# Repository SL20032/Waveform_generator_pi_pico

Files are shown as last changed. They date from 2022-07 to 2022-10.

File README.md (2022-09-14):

# Waveform_generator_pi_pico

<p align="center">
  
  
  
  
</p>

## Experimental: project in active development
Do not use 
## Basic Information
Projest aims to build simple waveform generator (with digitaly adjustable amplitude and offset of signal) based around AD9833 DDS chip controled via PC app. With digital and comunication part of the circutry beeing handled by RP2040 on Pi Pico board. 

## Hardware
hardware part of this projest consst of two main elements:
### Analog
Responsible for generating (AD9833) and ampifaing and offsetting (pair of LM7171) analog signal. As well as aditional components needed for example for square wave processing. (attached baord layout require redesign for proper operation of offset capability - work in progress)

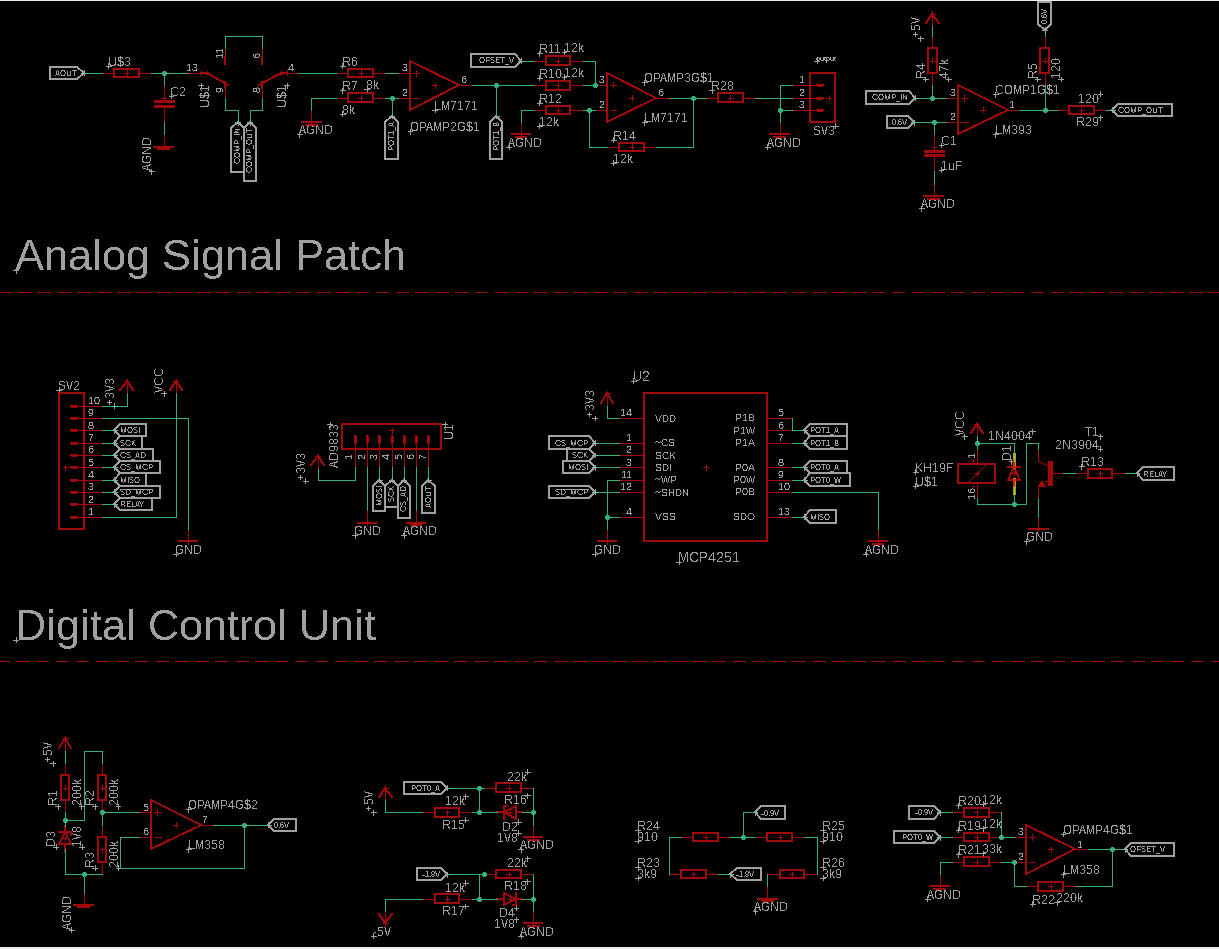
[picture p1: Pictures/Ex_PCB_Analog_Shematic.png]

### Digital
Responsible for controling analog part of circutry using digital potenciometers (MCP4231 / MC4251) integrated on analog board prototype as well as comunication with PC using galvanicly isoleded interfece.
## PC Software
Coming soon

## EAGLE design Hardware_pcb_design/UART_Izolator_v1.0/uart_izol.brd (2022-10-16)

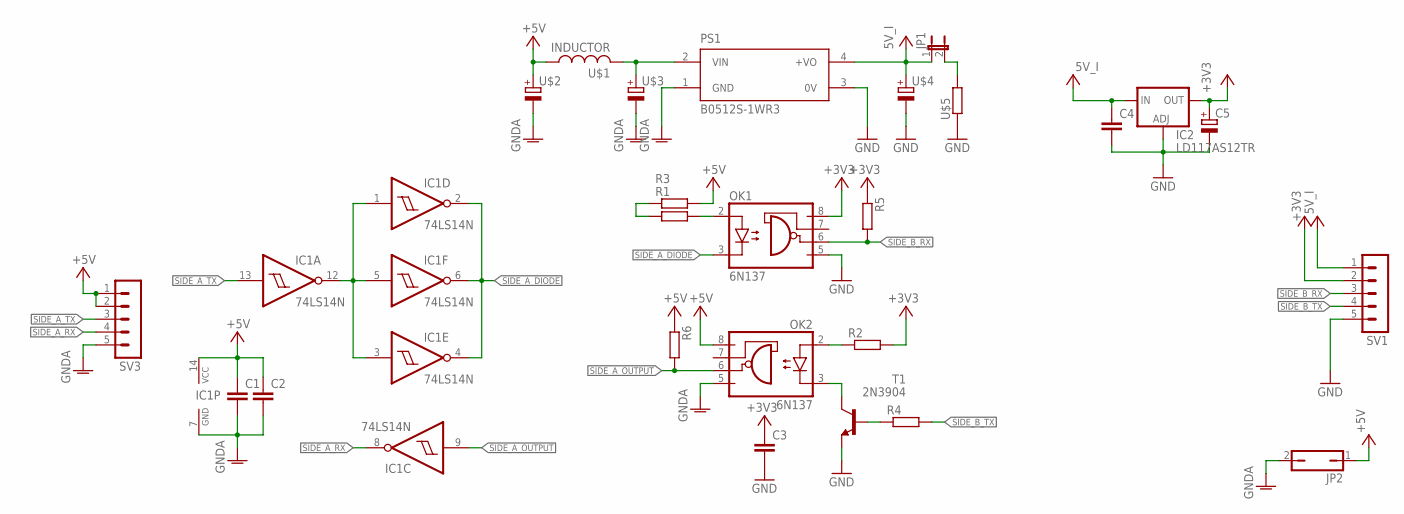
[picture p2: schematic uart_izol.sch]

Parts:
C1, C2, C3, C4: C-EUC0805; C0805
C5: CPOL-EUSMCB; SMC_B
IC1: 74LS14N; DIL14
IC2: LD117AS12TR; SOT223
JP1: JP1E; JP1
JP2: JP1Q; JP1
OK1, OK2: 6N137; DIL08
PS1: B0512S-1WR3; CONV_B0512S-1WR3
R1, R2, R3, R4, R5, R6: R-EU_M0805; M0805
SV1, SV3: MA05-1
T1: 2N3904; TO92
U$1: INDUCTOR; 0207/10
U$2, U$3, U$4: CAPACITOR; E2,5-7
U$5: RESISTOR; 0207/10

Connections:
+3V3: C3.1, C5.+, IC2.4 (OUT), OK1.8 (VCC), R2.2, R5.1, SV1.2
+5V: C1.1, C2.1, IC1.14 (VCC), JP2.1, OK2.8 (VCC), R3.2, R6.1, SV3.1, SV3.2, U$1.1, U$2.+
GND: C3.2, C4.2, C5.-, IC2.1 (ADJ), OK1.5 (GND), PS1.3 (0V), SV1.5, T1.3 (E), U$4.-, U$5.1
GNDA: C1.2, C2.2, IC1.7 (GND), JP2.2, OK2.5 (GND), PS1.1 (GND), SV3.5, U$2.-, U$3.-
unnamed: OK1.2 (A), R1.2
unnamed: OK2.2 (A), R2.1
unnamed: R1.1, R3.1
unnamed: OK2.3 (C), T1.1 (C)
unnamed: JP1.2, U$5.2
unnamed: R4.1, T1.2 (B)
unnamed: PS1.2 (VIN), U$1.2, U$3.+
unnamed: IC1.1 (I), IC1.3 (I), IC1.5 (I), IC1.12 (O)
SIDE_A_DIODE: IC1.2 (O), IC1.4 (O), IC1.6 (O), OK1.3 (C)
SIDE_A_OUTPUT: IC1.9 (I), OK2.6 (VO), R6.2
SIDE_A_RX: IC1.8 (O), SV3.4
SIDE_A_TX: IC1.13 (I), SV3.3
SIDE_B_RX: OK1.6 (VO), R5.2, SV1.3
SIDE_B_TX: R4.2, SV1.4
VCC: C4.1, IC2.3 (IN), JP1.1, PS1.4 (+VO), SV1.1, U$4.+

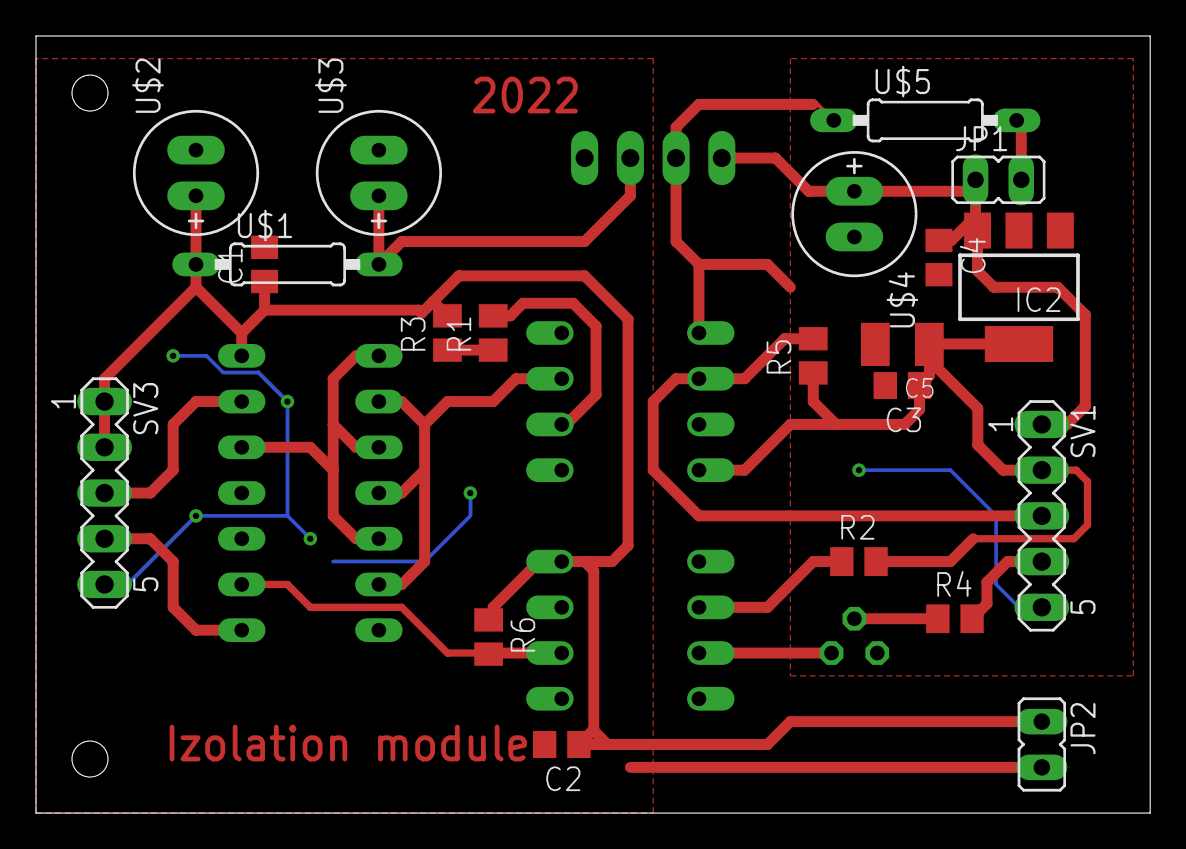
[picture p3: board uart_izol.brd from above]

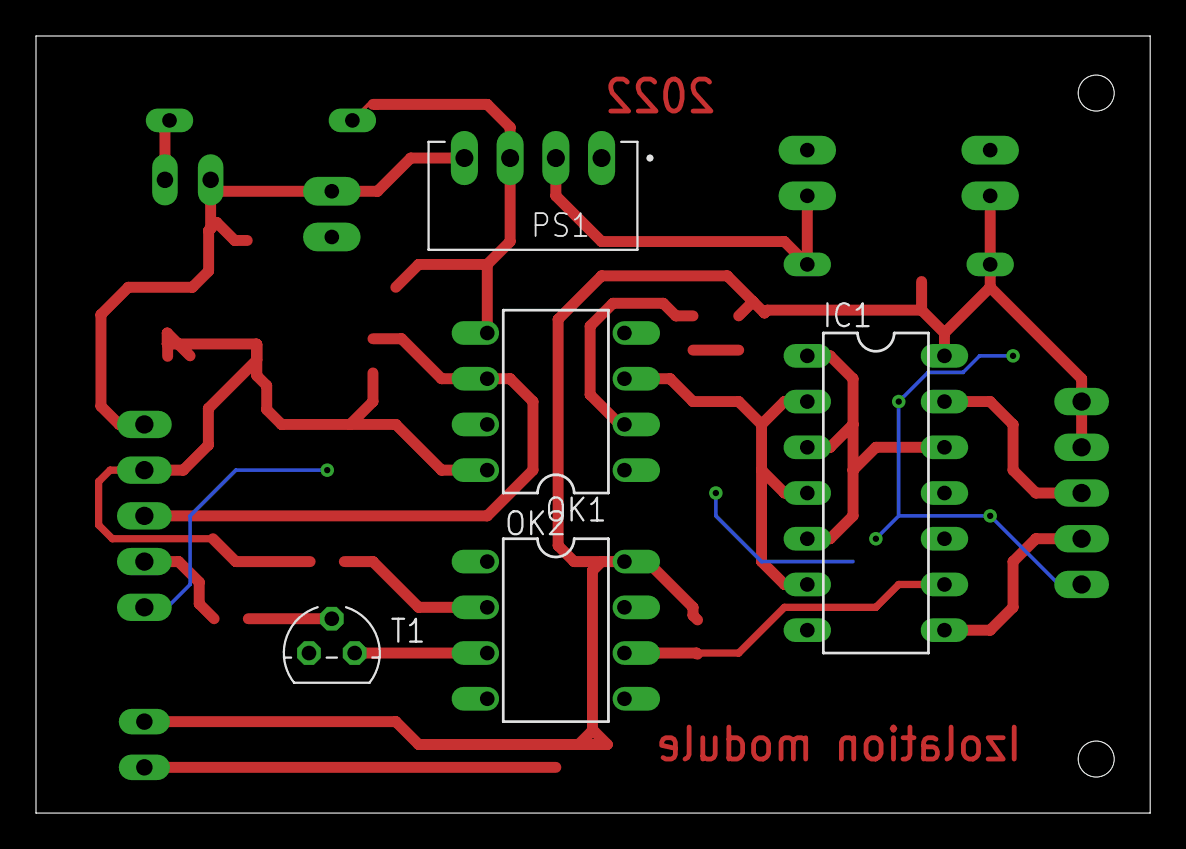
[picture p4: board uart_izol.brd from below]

Board: 2 copper layers, 61.9 x 43.2 mm, 26 parts (5 on the bottom side), 19 nets.

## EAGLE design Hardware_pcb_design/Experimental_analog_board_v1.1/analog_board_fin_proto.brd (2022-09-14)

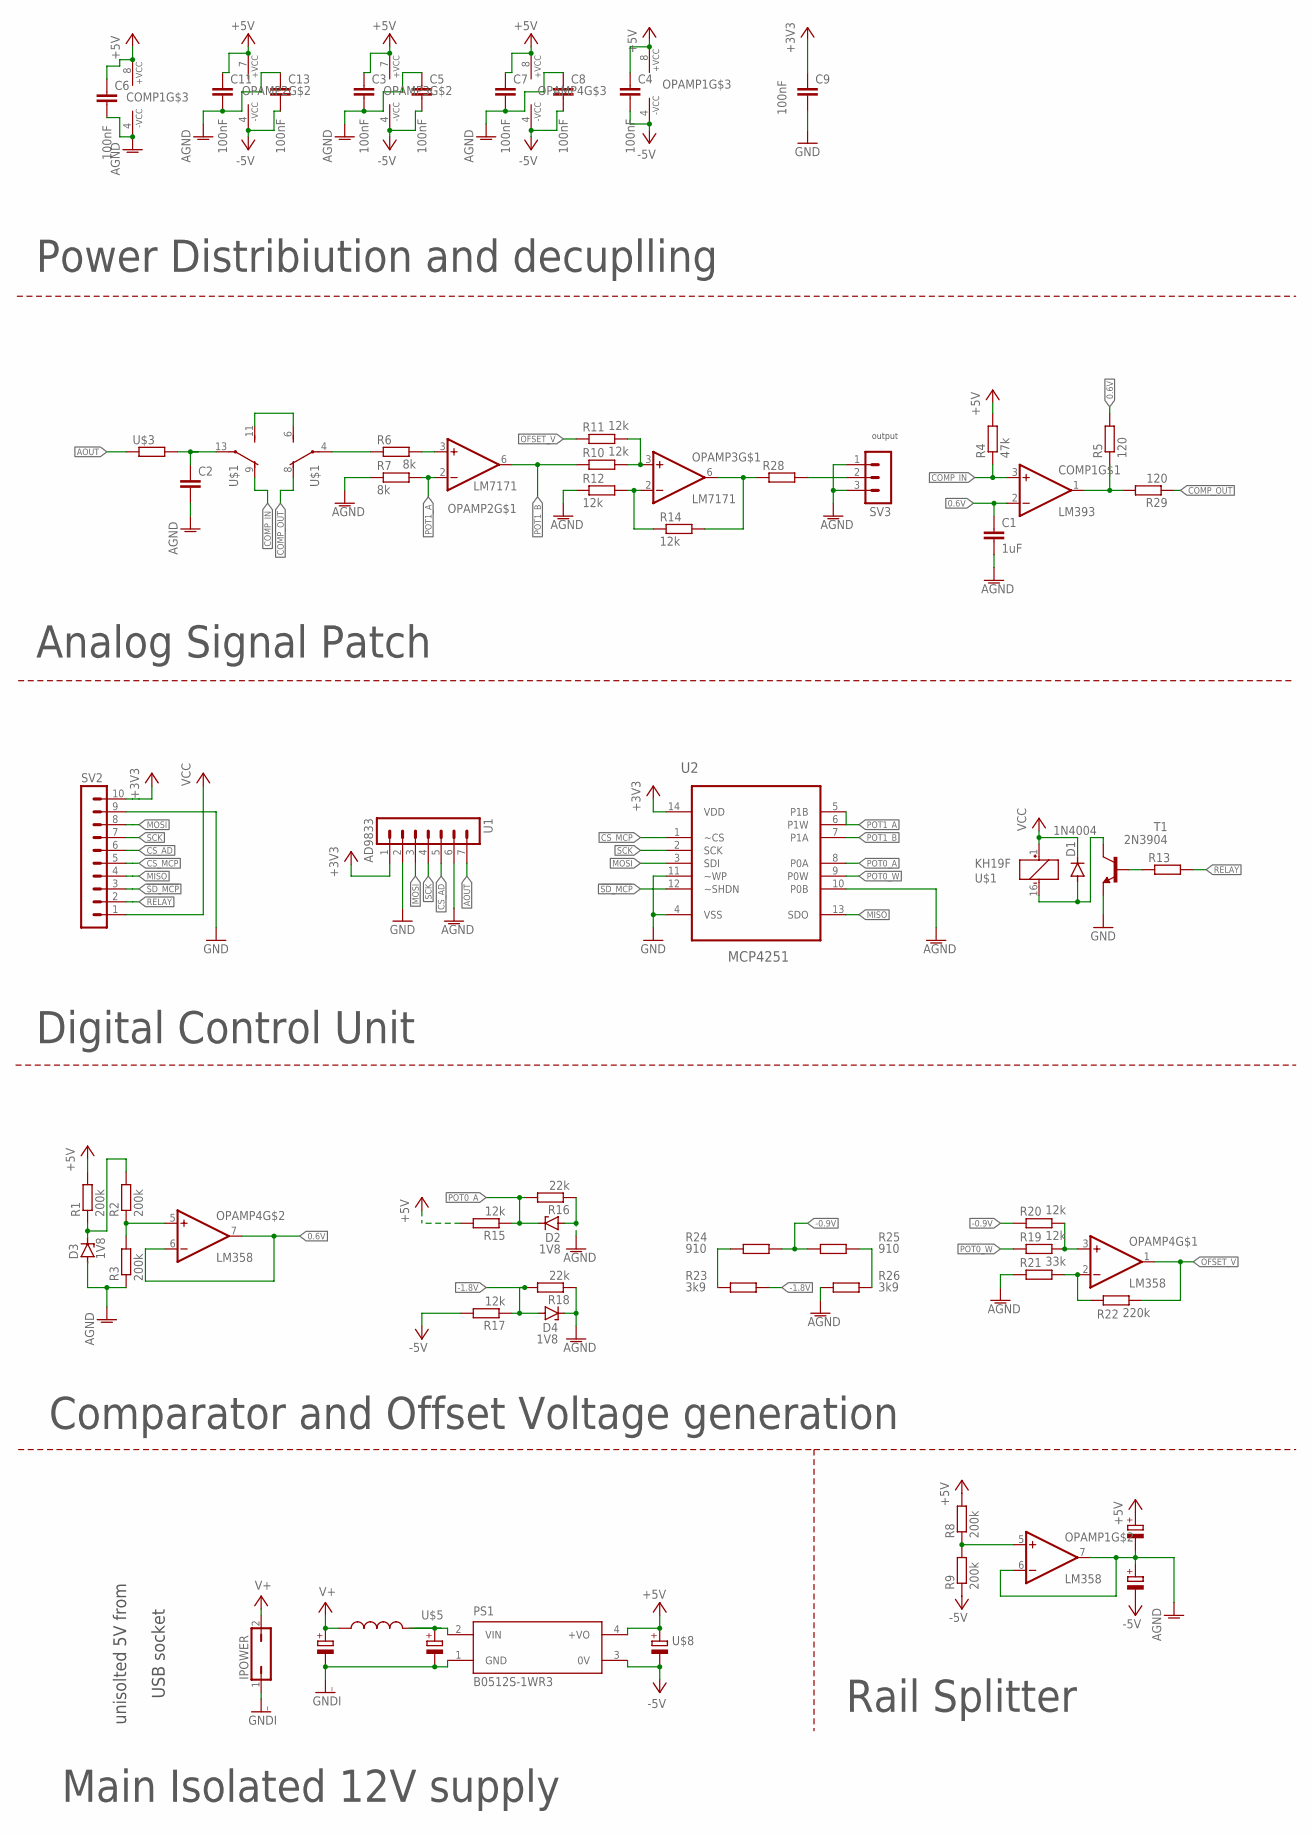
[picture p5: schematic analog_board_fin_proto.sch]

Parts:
C1: 1uF; C0805
C2: C-EU025-025X050; C025-025X050
C3, C4, C5, C6, C7, C8, C9, C11, C13: 100nF; C0805
COMP1: LM393; DIL08
D1: 1N4004; DO41-10
D2, D3, D4: 1V8; SOD80C
IPOWER: POT; JP1
OPAMP1, OPAMP4: LM358; DIL08
OPAMP2, OPAMP3: LM7171; DIL08
PS1: B0512S-1WR3; CONV_B0512S-1WR3
R1, R2, R3, R8, R9: 200k; R0805
R4: 47k; R0805
R5, R29: 120; R0805
R6, R7: 8k; R0805
R10, R11, R12, R14, R15, R17, R19, R20: 12k; R0805
R13: R-EU_R0805; R0805
R16, R18: 22k; R0805
R21: 33k; R0805
R22: 220k; R0805
R23, R26: 3k9; R0805
R24, R25: 910; R0805
R28: R-EU_R2512; R2512
SV2: MA10-1
SV3: MA03-1
T1: 2N3904; TO92
U1: AD9833; MA07-1
U2: MCP4251; DIL14
U$1: KH19F; BT-XX-S
U$3: RESISTOR; 0207/10
U$5, U$8, U$9, U$10: CAPACITOR; E2,5-7
U$6: 100nF; E2,5-7
U$7: INDUCTOR; 0207/10

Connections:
0.6V: C1.1, COMP1.2 (-IN), OPAMP4.6 (-IN), OPAMP4.7 (OUT), R5.2
!SD_MCP: SV2.3, U2.12 (~SHDN)
+3V3: C9.1, SV2.10, U1.1, U2.14 (VDD)
+5V: C3.1, C4.1, C6.1, C7.1, C11.1, COMP1.8 (VCC), OPAMP1.8 (VCC), OPAMP2.7 (VCC), OPAMP3.7 (VCC), OPAMP4.8 (VCC), PS1.4 (+VO), R1.2, R4.2, R8.2, R15.2, U$8.+, U$9.+
-0.9V: R20.1, R24.1, R25.2
-1.8V: D4.A, R17.1, R18.2, R23.2
-5V: C4.2, C5.2, C8.2, C13.2, OPAMP1.4 (GND), OPAMP2.4 (GND), OPAMP3.4 (GND), OPAMP4.4 (GND), PS1.3 (0V), R9.1, R17.2, U$8.-, U$10.-
AGND: C1.2, C2.2, C3.2, C5.1, C6.2, C7.2, C8.1, C11.2, C13.1, COMP1.4 (GND), D2.A, D3.A, D4.C, OPAMP1.6 (-IN), OPAMP1.7 (OUT), R3.1, R7.1, R12.1, R16.1, R18.1, R21.1, R26.1, SV3.1, SV3.3, U1.6, U2.10 (P0B), U$9.-, U$10.+
AOUT: U1.7, U$3.1
COMP_IN: COMP1.3 (+IN), R4.1, U$1.9 (O)
COMP_OUT: R29.1, U$1.8 (O)
CS_AD: SV2.6, U1.5
CS_MCP: SV2.5, U2.1 (~CS)
GND: C9.2, SV2.9, T1.3 (E), U1.2, U2.4 (VSS), U2.11 (~WP)
GNDI: IPOWER.1, PS1.1 (GND), U$5.-, U$6.-
MISO: SV2.4, U2.13 (SDO)
MOSI: SV2.8, U1.3, U2.3 (SDI)
unnamed: OPAMP4.5 (+IN), R2.1, R3.2
unnamed: U$1.6 (S), U$1.11 (S)
unnamed: C2.1, U$1.13, U$3.2
unnamed: D3.C, R1.1, R2.2
unnamed: OPAMP3.3 (+IN), R10.2, R11.2
unnamed: R6.1, U$1.4
unnamed: OPAMP3.6 (OUT), R14.2, R28.1
unnamed: OPAMP3.2 (-IN), R12.2, R14.1
unnamed: OPAMP1.5 (+IN), R8.1, R9.2
unnamed: OPAMP4.3 (+IN), R19.2, R20.2
unnamed: R28.2, SV3.2
unnamed: OPAMP2.3 (+IN), R6.2
unnamed: R23.1, R24.2
unnamed: OPAMP4.2 (-IN), R21.2, R22.1
unnamed: R25.1, R26.2
unnamed: PS1.2 (VIN), U$5.+, U$7.2
unnamed: D1.A, T1.1 (C), U$1.16 (-)
unnamed: COMP1.1 (OUT), R5.1, R29.2
unnamed: R13.1, T1.2 (B)
OFSET_V: OPAMP4.1 (OUT), R11.1, R22.2
POT0_A: D2.C, R15.1, R16.2, U2.8 (P0A)
POT0_W: R19.1, U2.9 (P0W)
POT1_A: OPAMP2.2 (-IN), R7.2, U2.5 (P1B), U2.6 (P1W)
POT1_B: OPAMP2.6 (OUT), R10.1, U2.7 (P1A)
RELAY: R13.2, SV2.2
SCK: SV2.7, U1.4, U2.2 (SCK)
V+: IPOWER.2, U$6.+, U$7.1
VCC: D1.C, SV2.1, U$1.1 (+)

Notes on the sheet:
unisolted 5V from
USB socket
Main Isolated 12V supply
Rail Splitter
Comparator and Offset Voltage generation
output
Digital Control Unit
Analog Signal Patch
Power Distribiution and decuplling

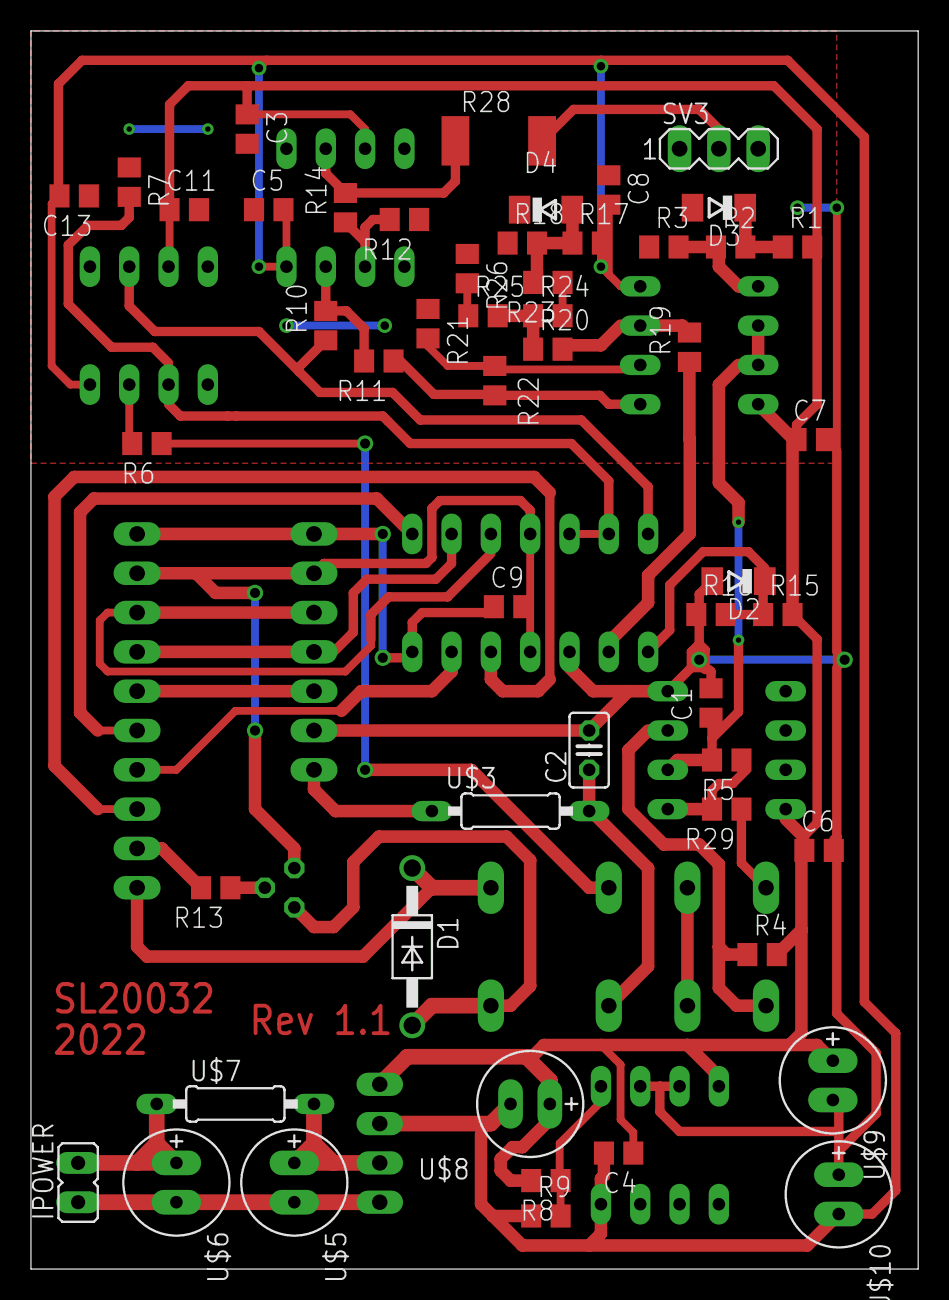
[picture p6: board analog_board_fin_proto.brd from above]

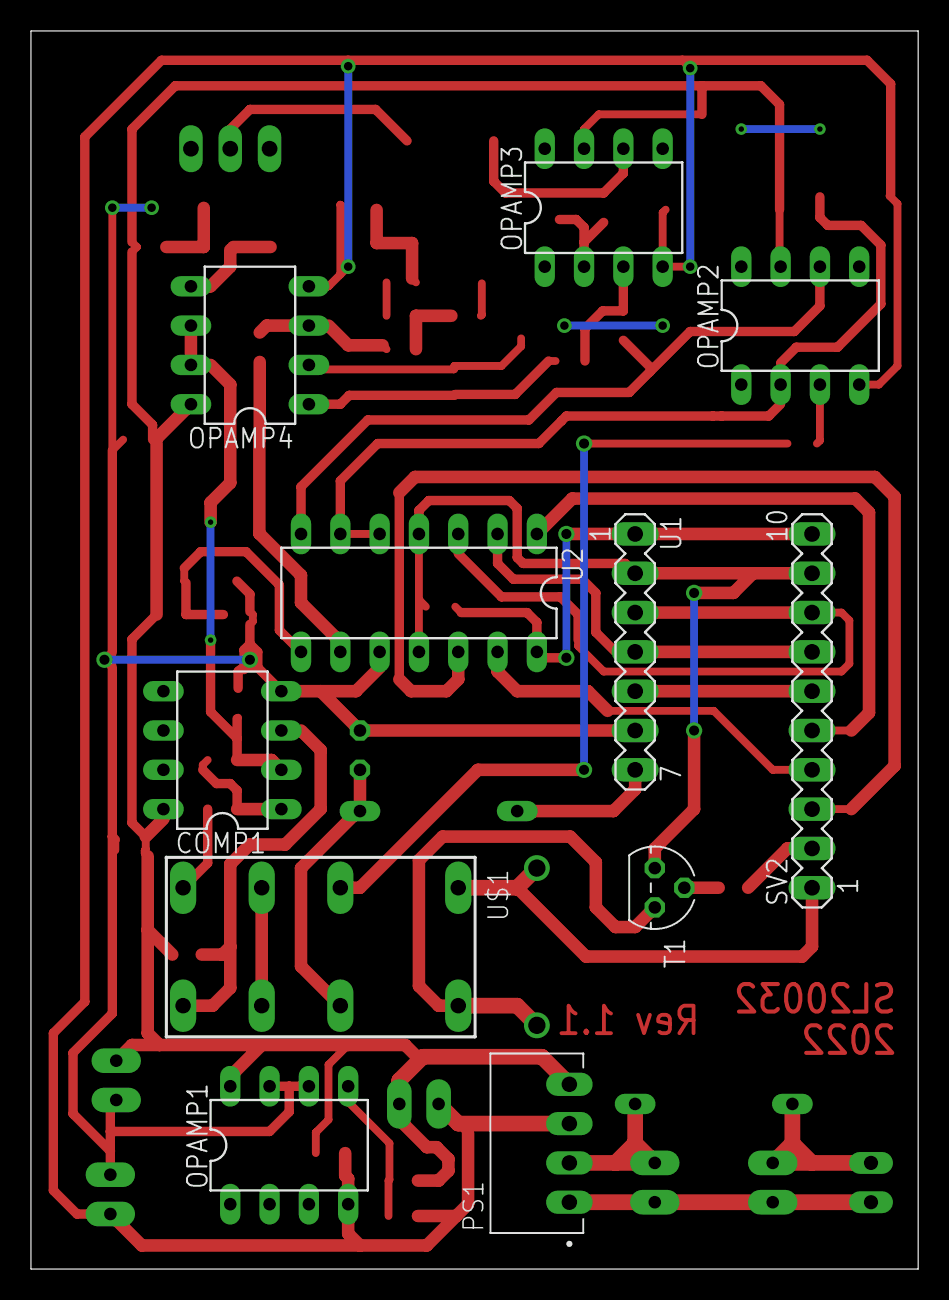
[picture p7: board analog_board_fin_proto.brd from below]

Board: 2 copper layers, 57.3 x 80.0 mm, 63 parts (11 on the bottom side), 45 nets.

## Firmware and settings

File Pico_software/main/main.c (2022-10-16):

#include "pico/stdlib.h"
#include "AD9833.h"
#include "PWM.h"
#include "SPI.h"
#include "UART.h"
#include "PCM4251.h"

#include "hardware/uart.h"

#define ONBOARD_LED 25

char Input_arr[10];
char test_arr[10] = {0x41, 0x54, 0x2b, 80, 0, 0, 0, 10, 40, 0xEE};

int main() 
{
	SPI_main_init();
	SPI_sec_init();
	UART_Init(Input_arr);

	gpio_init(ONBOARD_LED);
	gpio_set_dir(ONBOARD_LED,true);
	gpio_put(ONBOARD_LED,1);

	AD9833_Set_Freq(1000,AD9833_SINE);
	sleep_us(100);
	PCM4251_set_potenciometer_position(5,80);

	sleep_ms(1000);
	//UART_Write(test_arr,10);
	UART_Write("Generator software v01",22);

	while (true) {
		if(UART_is_new_data_avalible())
		{
			//checking CRC
			if (/*check_crc(Input_arr,6)*/true)
			{
				uint8_t temp_sig_type;

				switch (Input_arr[3])
				{
				case 0:
					temp_sig_type = AD9833_SINE;
					break;
				case 1:
					temp_sig_type = AD9833_TRIG;
					break;
				case 2:
					temp_sig_type = AD9833_SQER;
					break;
				}
				
				AD9833_Set_Freq(Input_arr[2] + (Input_arr[1] << 8) + (Input_arr[0] << 16),temp_sig_type);
				PCM4251_set_potenciometer_position(Input_arr[4],Input_arr[5]);
				UART_Write("OK",2);
			}
			else UART_Write("FAIL",4);
		}
	}
}

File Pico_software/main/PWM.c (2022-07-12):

#include "PWM.h"

uint PWM0_slice_num = 0;
uint PWM0_chan_num = 0;

void PWM0_Init(void)
{
    //seting gpio func
    gpio_set_function(PWM_PIN,GPIO_FUNC_PWM);

    //PWM config struct
    pwm_config PWM0_config = pwm_get_default_config(); 
    pwm_config_set_clkdiv(&PWM0_config, (float)1);
    pwm_config_set_wrap(&PWM0_config,0xFFFF);
    
    //PWM clock setings (slice)
    PWM0_slice_num = pwm_gpio_to_slice_num(PWM_PIN);    //check witch PWM clock powers gpio pin
	PWM0_chan_num = pwm_gpio_to_channel(PWM_PIN);
    pwm_init(PWM0_slice_num, &PWM0_config, false);

}

void PWM0_enable(void)
{
    pwm_set_enabled(PWM0_slice_num, true);
}

void PWM0_disable(void)
{
    pwm_set_enabled(PWM0_slice_num, false);
}

uint8_t CALC_best_clk_div(uint32_t target_freq)
{
    uint8_t div = 1;
    uint8_t best_div = 0;
    double freq_test = 0;
    double diviation = 0;
    double best_diviation = 0;
    uint32_t pwm_wrap = 0;

    if (target_freq > PWM_MAX_FREQ) target_freq = PWM_MAX_FREQ;    

    for (div = 1;div < 30;div++)
    {
        pwm_wrap = (PWM_CLK / (target_freq * div)) - 1;
        if (pwm_wrap < 65536 && pwm_wrap > 100)
        {
            freq_test = ((double)PWM_CLK / ((pwm_wrap + 1) * div));
            diviation = fabs((double)freq_test - target_freq);
            if (diviation < best_diviation ^ (best_diviation == 0 && best_div == 0))
            {
                best_div = div;
                best_diviation = diviation;
            }
        }  
    }

    return best_div;
}

uint32_t CALC_wrap(uint32_t target_freq, uint8_t div)
{
    uint16_t pwm_wrap;
    if (target_freq > PWM_MAX_FREQ) target_freq = PWM_MAX_FREQ;
    pwm_wrap = (PWM_CLK / (target_freq * div)) - 1;

    return pwm_wrap;
}

/*
*  Function for setting freq and duty of PWM0 
* (duty param values 0 - 100)
* (target freq max 100 000)
*/
void PWM0_set_freq_and_duty(uint32_t target_freq, uint8_t duty)
{
    uint8_t div = CALC_best_clk_div(target_freq);
    uint16_t wrap = CALC_wrap(target_freq, div);
    
    pwm_set_clkdiv(PWM0_slice_num, (float)div);
    pwm_set_wrap(PWM0_slice_num, wrap);
    pwm_set_chan_level(PWM0_slice_num, PWM0_chan_num, (wrap / 100) * duty);
}

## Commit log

2022-07-10 Add DMA driven SPI Interface (#2)
2022-07-10 Implement AD9833 Driver (#3)
2022-07-12 Add simple PWM driver (#4)
2022-09-14 ADD MCP4231/4251 support + prototype integration
2022-09-14 Add Experimental Analog PCB and read me
    [analog_board_fin_proto.brd, analog_board_fin_proto.sch]
2022-09-16 Implementation of UART interfrce via DMA
2022-09-16 Implementation of UART interfrce via DMA 2
2022-09-16 UART Integration
2022-10-16 Add USAR izolator PCB files
    [uart_izol.brd, uart_izol.sch]
